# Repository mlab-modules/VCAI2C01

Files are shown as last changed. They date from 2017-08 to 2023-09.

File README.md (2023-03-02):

<!--- PrjInfo ---> <!--- Please remove this line after manually editing --->
<!--- 00a56be08b96043df9e37d6aff7b6990 --->
<!--- Created:2019-02-18 14:36:04.428293: ---> 
<!--- Author:: ---> 
<!--- AuthorEmail:: ---> 
<!--- Tags:: ---> 
<!--- Ust:: ---> 
<!--- Label --->
<!--- ELabel ---> 
<!--- Name:VCAI2C01A: --->
# VCAI2C01A
<!--- LongName --->
## AD converter voltage and current with I2C
<!--- ELongName ---> 

<!--- Lead --->
4-channel 18-bit AD converter voltage and current for industrial sensors. Ranges: 0-5V, 0-10V, 0-20mA, 4-20mA, 0-40 mA.
<!--- ELead ---> 

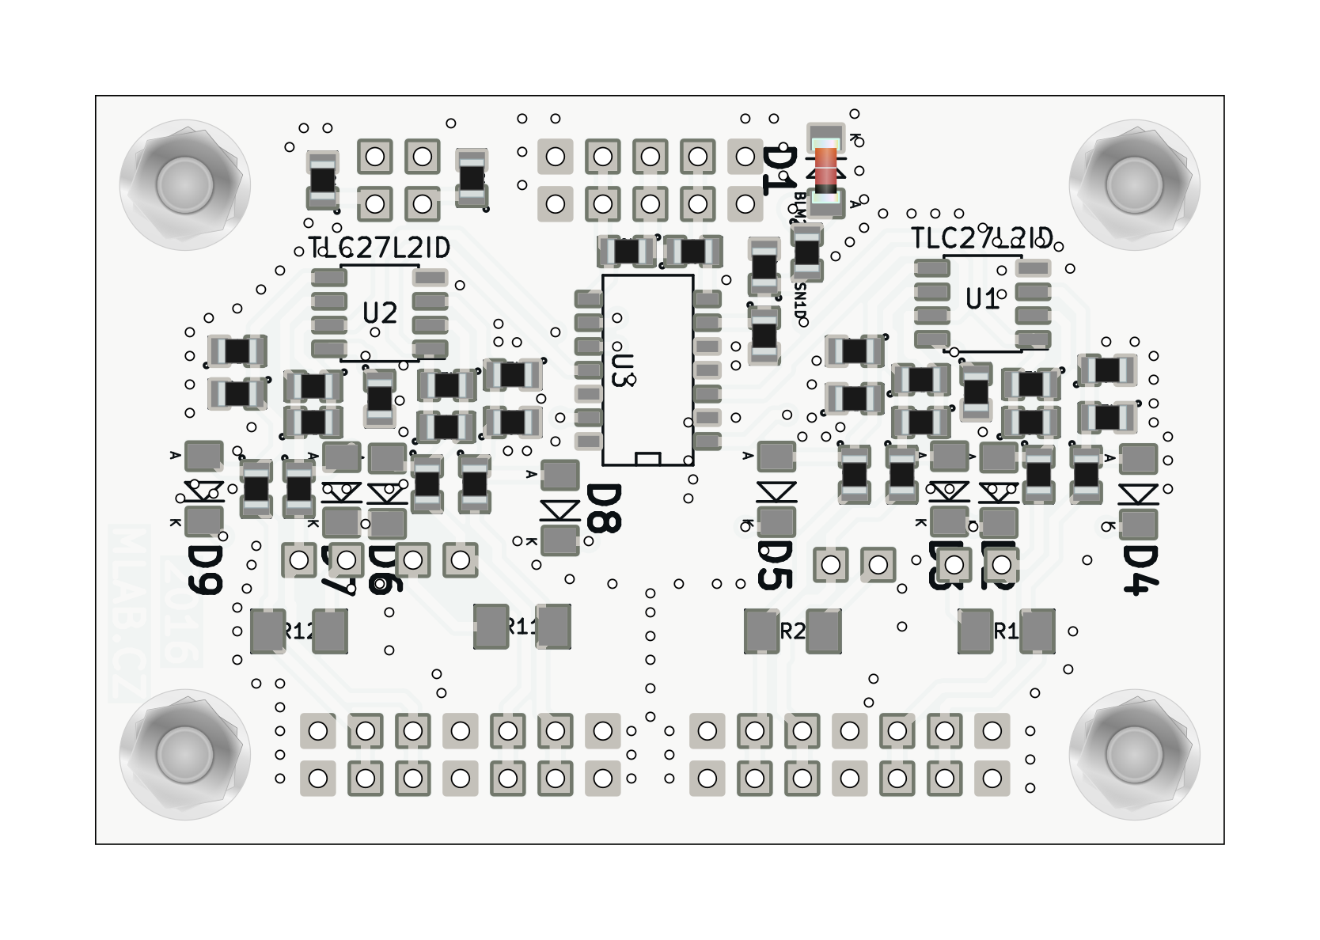
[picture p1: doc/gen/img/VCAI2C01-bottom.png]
VCAI2C01A bottom
 
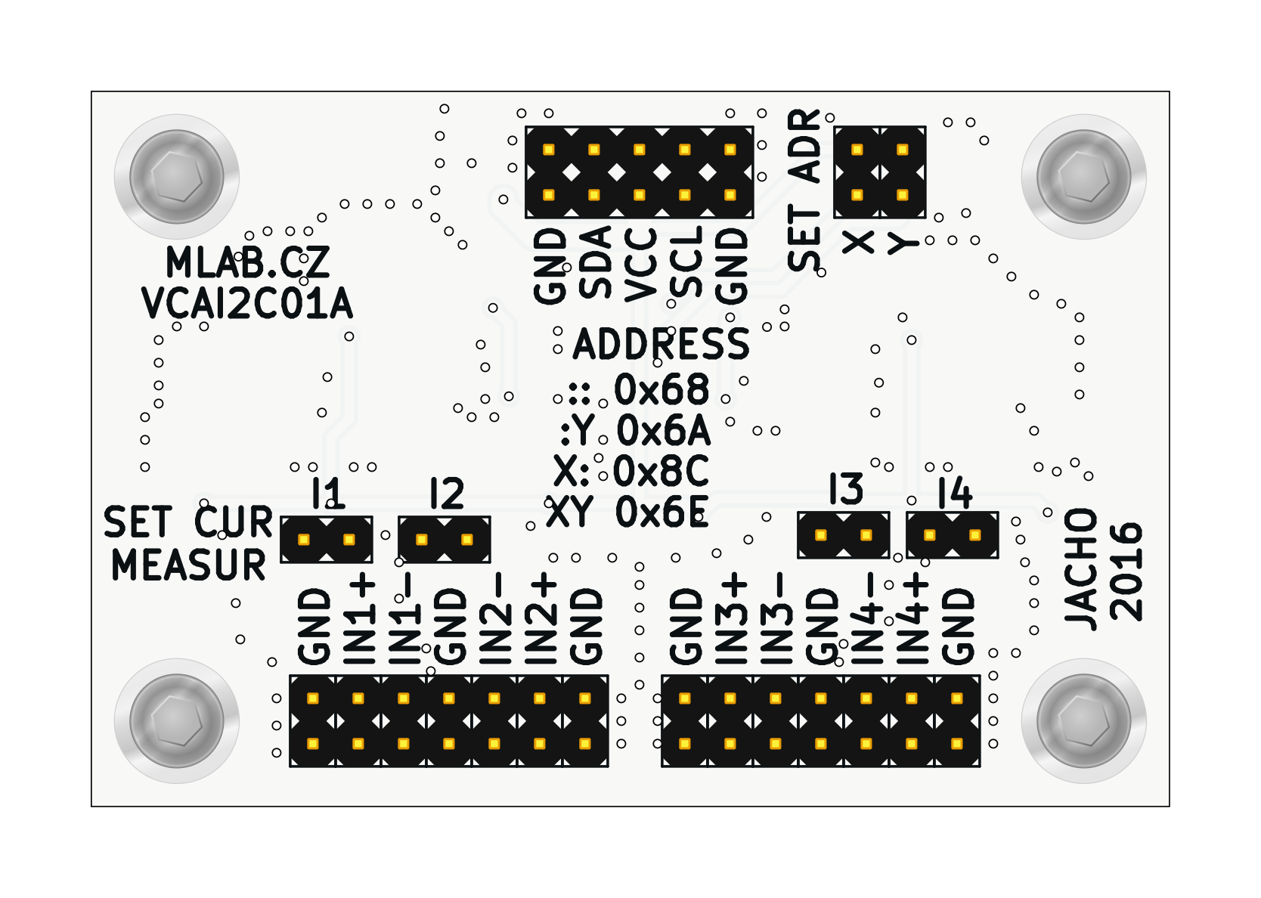
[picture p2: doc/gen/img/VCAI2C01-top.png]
VCAI2C01A bottom
 

<!--- Description --->
<!--- EDescription --->
<!--- Content --->
<!--- EContent --->
<sub><sup> Generated with [MLABweb](https://github.com/MLAB-project/MLABweb). (2019-02-18)</sup></sub>

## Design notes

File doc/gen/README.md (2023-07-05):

# PCB

Board size: 60.45x40.13 mm (2.38x1.58 inches)

- This is the size of the rectangle that contains the board
- Thickness: 1.6 mm (63 mils)
- Material: FR4
- Finish: HAL
- Layers: 2
- Copper thickness: 35 µm

Solder mask: TOP / BOTTOM

- Color: Green

Silk screen: TOP / BOTTOM

- Color: White

# Important sizes

Clearance: 0.25 mm (10 mils)

Track width: 0.3 mm (12 mils)

- By design rules: 0.2 mm (8 mils)

Drill: 0.5 mm (20 mils)

- Vias: 0.5 mm (20 mils) [Design: 0.4 mm (16 mils)]
- Pads: 1.0 mm (39 mils)
- The above values are real drill sizes, they add 0.1 mm (4 mils) to plated holes (PTH)

Via: 0.8/0.4 mm (31/16 mils)

- By design rules: 0.4/0.3 mm (16/12 mils)
- Micro via: yes [0.2/0.1 mm (8/4 mils)]
- Buried/blind via: yes
- Total: 162 (thru: 162 buried/blind: 0 micro: 0)

Outer Annular Ring: 0.15 mm (6 mils)

- By design rules: 0.26 mm (10 mils)

Eurocircuits class: 4B
- Using min drill 0.5 mm for an OAR of 0.15 mm

# General stats

Components count: (SMD/THT)

- Top: 0/25 (THT)
- Bottom: 49/0 (SMD)

Defined tracks:

- 0.3 mm (12 mils)
- 0.4 mm (16 mils)
- 0.5 mm (20 mils)
- 0.6 mm (24 mils)
- 0.7 mm (28 mils)
- 1.3 mm (51 mils)

Used tracks:

- 0.3 mm (12 mils) (231) defined: yes
- 0.5 mm (20 mils) (361) defined: yes
- 0.6 mm (24 mils) (21) defined: yes
- 0.7 mm (28 mils) (12) defined: yes
- 1.3 mm (51 mils) (11) defined: yes

Defined vias:

Used vias:

- 0.8/0.4 mm (31/16 mils) (Count: 162, Aspect: 2.0 A) defined: no

Holes (excluding vias):

- 0.89 mm (35 mils) (50)
- 3.0 mm (118 mils) (4)

Oval holes:

Drill tools (including vias and computing adjusts and rounding):

- 0.5 mm (20 mils) (162)
- 1.0 mm (39 mils) (50)
- 3.1 mm (122 mils) (4)

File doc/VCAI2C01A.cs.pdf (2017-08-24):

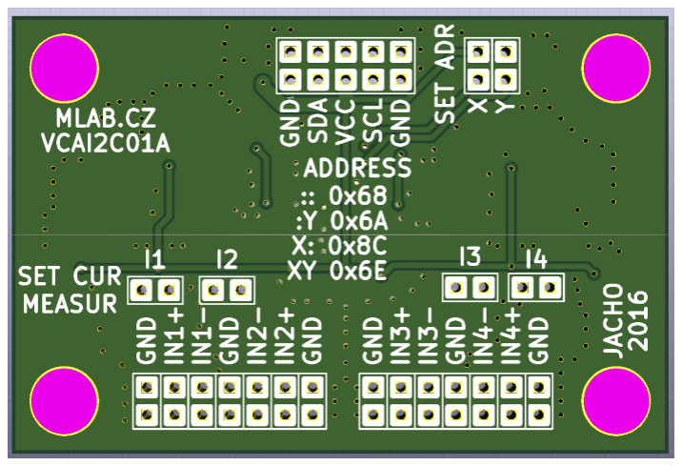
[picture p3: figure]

VCAI2C01A / 2016-10-04 / jacho/ http://www.mlab.cz | 1 / 5
VCAI2C01A | MLAB

# A/D převodník napětí a proudu s I2C

Jan Chroust

### Díky tomuto převodníku, je možné k systému založeném na modulech MLAB připojit standardní průmyslové senzory. Jedná se o

4 kanálový 18 bitový AD převodník.

# 1. Technické parametry

Parametr | Hodnota | Poznámka
Napájení | 5 V
Integrovaný obvod | MCP3424, TLC27L2ID
Využití | A/D převodník napětí a proudu
Rozsahy | 0-5V, 0-10V
| 0-20mA, 4-20mA, 0-40mA
Rozhraní | I2C
Rozměry | 60.45 x 40.13 x 16 mm | Výška nad základní deskou

VCAI2C01A | MLAB

# 2. Popis konstrukce

## 2.1. Popis

Jedná se o modul s 18 bitovým ∆∑ převodníkem. Umožňuje připojení standardních průmyslových senzorů, které využívají proudové smyčky, nebo napěťového výstupu. Komunikace s modulem probíhá přes I2C rozhraní. Na modulu je možné volit mezi čtveřicí adres. Pokud by bylo adres nedostatek, řešením je využití modulu I2CHUB02B. Pro aplikace, kde je potřeba větších vzdáleností v řádech desítek metrů od řídícího počítače, je k dispozici modul I2CDIFF01B. Kombinací modulů MLAB je možné navrhnout komplexní měřící zařízení.

### 2.1.1. Proudový režim

Pro kanály, kde chceme měřit proud je potřeba vložit jumper do řádky označené SET CUR MEASUR na příslušný kanál (I1, I2, I3, I4). Následně je možné na příslušný vstup připojit proudovou smyčku.

### 2.1.2. Napěťový režim

Jedná se o základní režim. Nesmí být vložen jumper do řádku s označením SET CUR MEASUR.

### 2.1.3. Volba I2C adresy

Na modulu je vyznačena tabulka I2C adres, které je možné volit konfigurací jumperů na hřebíncích označených SET ADR. Když není umístěn žádný jumper, tak adresa modulu je 0x68. Jedná se o 7bitovou adresu.

VCAI2C01A | MLAB

## 2.2. Zapojení

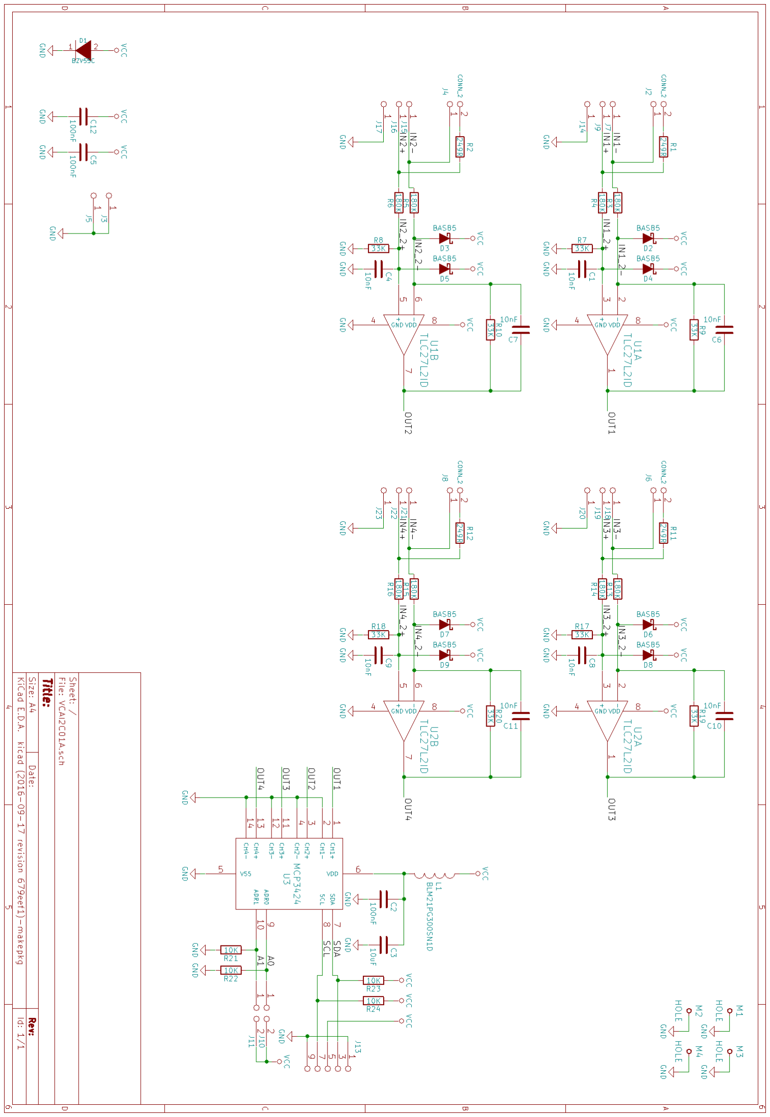
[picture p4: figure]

VCAI2C01A | MLAB

# 3. Osazení a oživení

## 3.1. Osazení

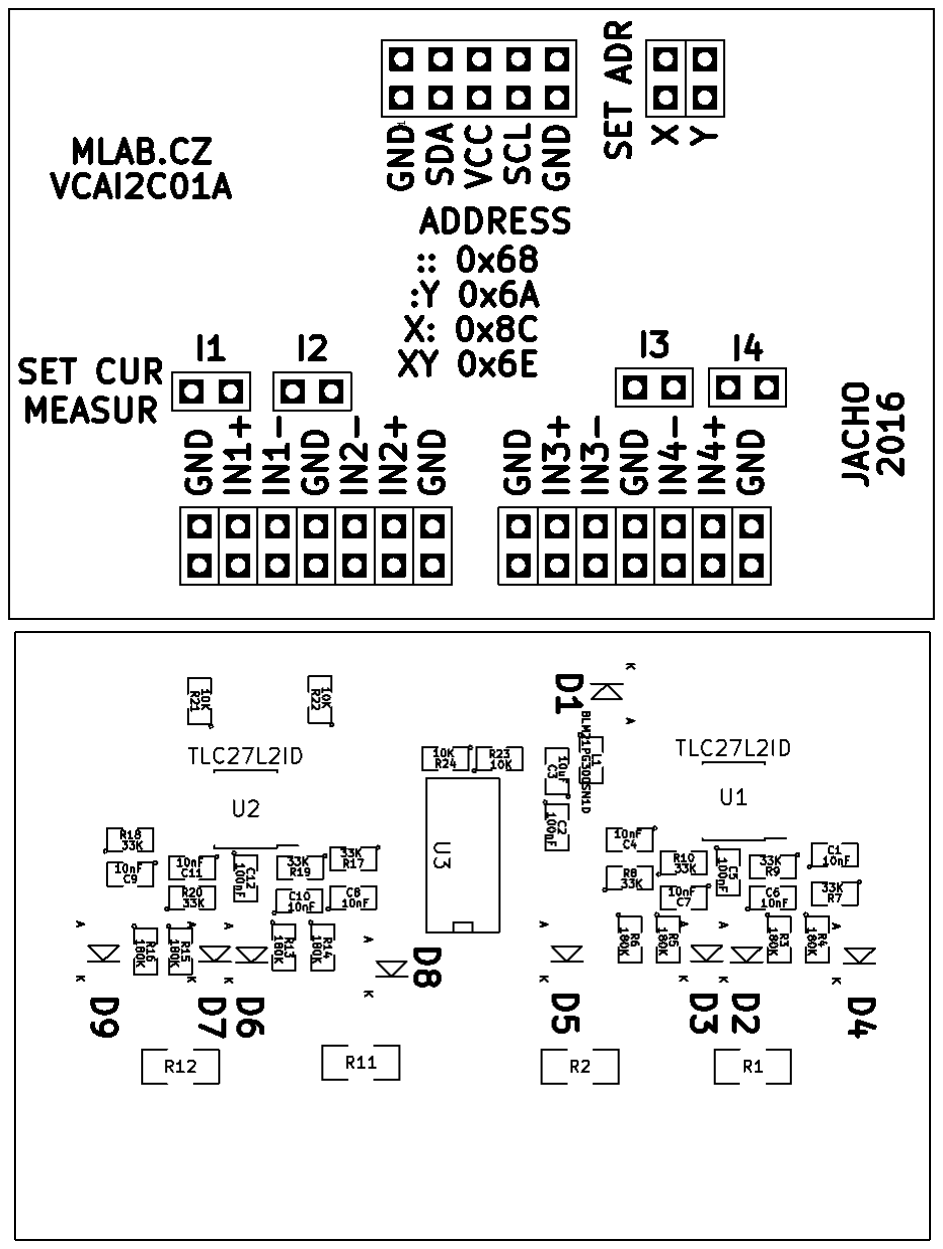
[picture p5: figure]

VCAI2C01A | MLAB

## 3.2. Rozpis součástek

Označení | Typ | Pouzdro | Počet
C1,C8,C6,C4,C7,C9,C10,C11 | 10nF | SMD-0805 | 8
R17,R19,R7,R8,R9,R10,R18,R20 | 33K | SMD-0805 | 8
U2,U1 | TLC27L2ID | SOIC-8_3.9x4.9mm_Pitch1.27mm | 2
R22,R21,R23,R24 | 10K | SMD-0805 | 4
D4,D2,D3,D5,D6,D7,D8,D9 | BAS85 | MiniMELF_Standard | 8
C2,C5,C12 | 100nF | SMD-0805 | 3
C3 | 10uF | SMD-0805 | 1
D1 | BZV55C | Diode-MiniMELF_Standard | 1
J2,J4,J6,J8 | CONN_2 | Straight_1x02 | 4
J10,J11 | JUMP2_2x1 | Straight_2x01 | 2
J13 | JUMP_5X2 | Straight_2x05 | 1
M1,M2,M3,M4 | HOLE | MountingHole_3mm | 4
R3,R4,R5,R6,R13,R14,R15,R16 | 180K | SMD-0805 | 8
U3 | MCP3424 | SOIC-14 | 1
J14,J15,J16,J17,J18,J19,J20,J21,J22,J23,J5 ,J7,J9 | JUMP_2x1 | Straight_1x02 | 13
J3 | JUMP_2x1 | Straight_2x01 | 1
L1 | BLM21PG300SN1D | SMD-0805 | 1
R1,R2,R11,R12 | 249R | SMD-1206 | 4

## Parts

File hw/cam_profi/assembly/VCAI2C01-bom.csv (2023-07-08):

Component | Description | Part | References | Value | Footprint | Quantity Per PCB | Datasheet
1 |  | C | C1C4C6C7C8C9C10C11 | 10nF | SMD-0805 | 8
2 |  | C | C2C5C12 | 100nF | SMD-0805 | 3
3 |  | C | C3 | 10uF | SMD-0805 | 1
4 |  | D_Schottky | D2D3D4D5D6D7D8D9 | BAS85 | MiniMELF_Standard | 8
5 |  | DIODE | D1 | BZV55C | Diode-MiniMELF_Standard | 1
6 |  | CONN_2 | J2J4J6J8 | CONN_2 | Straight_1x02 | 4
7 |  | JUMP2_2x1 | J10J11 | JUMP2_2x1 | Straight_2x01 | 2
8 |  | JUMP_2x1 | J5J7J9J14J15J16J17J18J19J20J21J22J23 | JUMP_2x1 | Straight_1x02 | 13
9 |  | JUMP_2x1 | J3 | JUMP_2x1 | Straight_2x01 | 1
10 |  | JUMP_5X2 | J13 | JUMP_5X2 | Straight_2x05 | 1
11 |  | INDUCTOR_SMALL | L1 | BLM21PG300SN1D | SMD-0805 | 1
12 |  | R | R1R2R11R12 | 249R | SMD-1206 | 4
13 |  | R | R21R22R23R24 | 10K | SMD-0805 | 4
14 |  | R | R7R8R9R10R17R18R19R20 | 33K | SMD-0805 | 8
15 |  | R | R3R4R5R6R13R14R15R16 | 180K | SMD-0805 | 8
16 |  | MCP3424 | U3 | MCP3424 | SOIC-14 | 1
17 |  | TLC27L2ID | U1U2 | TLC27L2ID | SOIC-8_3.9x4.9mm_Pitch1.27mm | 2

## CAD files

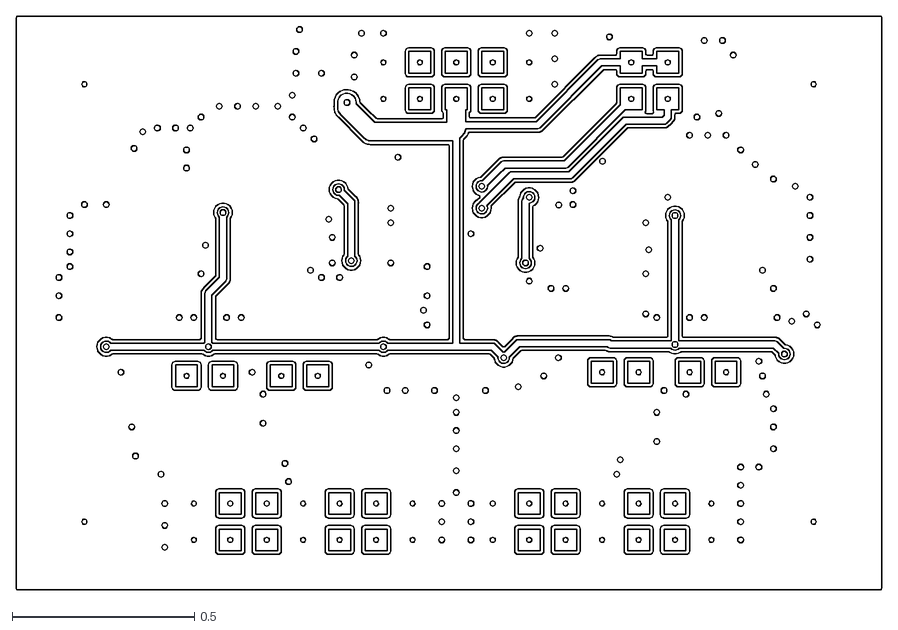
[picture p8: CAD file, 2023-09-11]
doc/gen/dxf/VCAI2C01-F_Cu.dxf
2.37 x 1.57

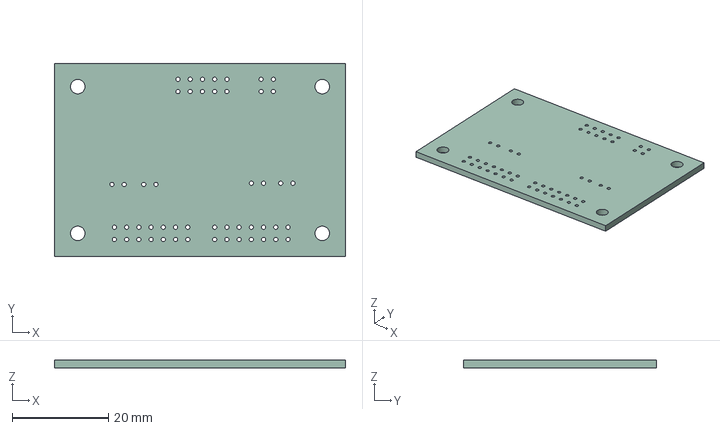
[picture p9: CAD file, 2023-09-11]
doc/gen/VCAI2C01.step
60.5 x 40.1 x 1.60 mm

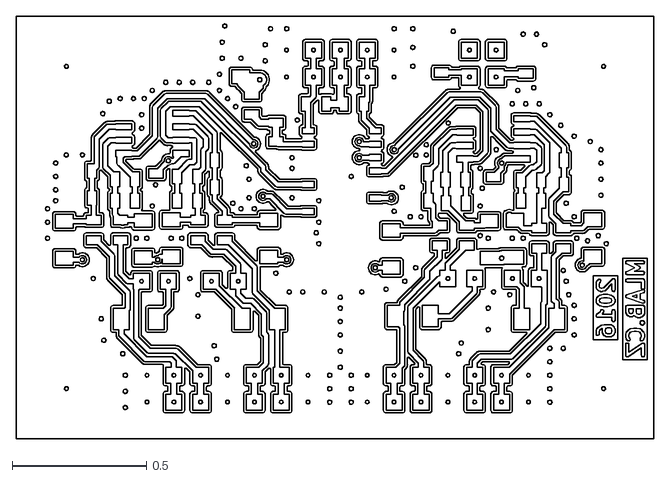
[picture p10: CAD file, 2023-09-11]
doc/gen/dxf/VCAI2C01-B_Cu.dxf
2.37 x 1.57

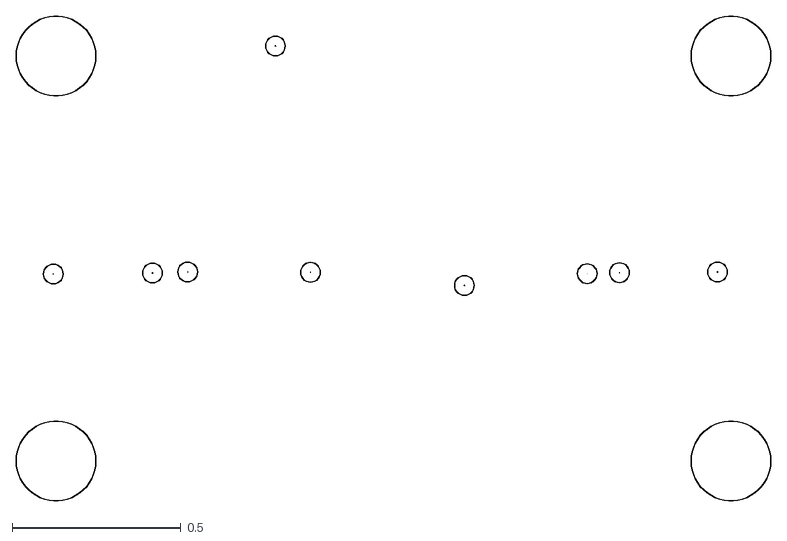
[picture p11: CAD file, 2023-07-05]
doc/gen/dxf/VCAI2C01-B_Adhesive.dxf
2.24 x 1.44

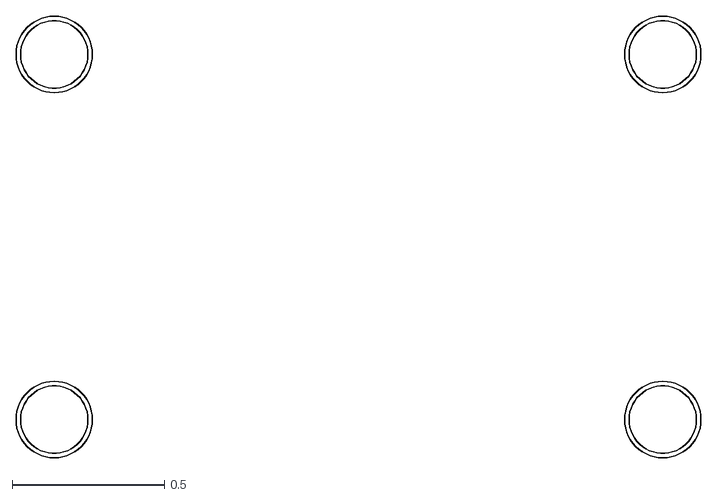
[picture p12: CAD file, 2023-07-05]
doc/gen/dxf/VCAI2C01-User_Comments.dxf
2.25 x 1.45

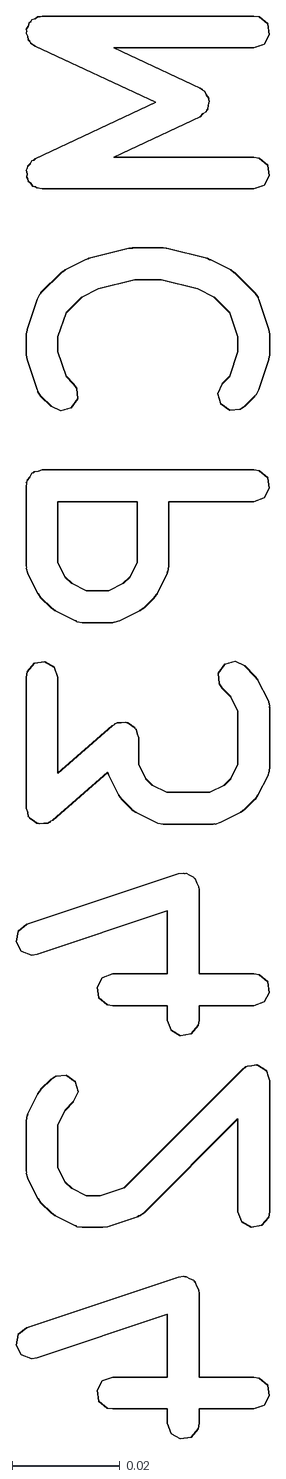
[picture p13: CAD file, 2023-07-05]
doc/gen/dxf/VCAI2C01-B_Fab.dxf
0.0471 x 0.265

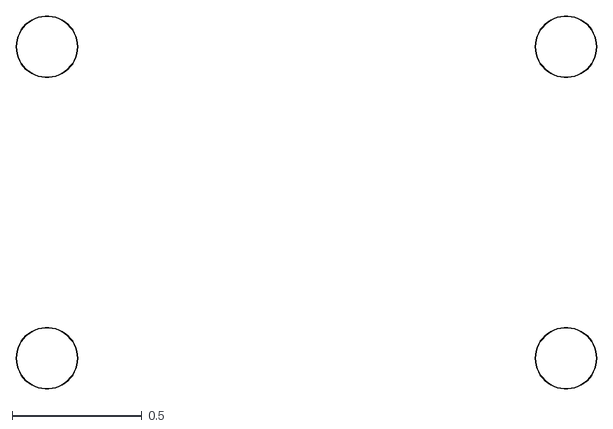
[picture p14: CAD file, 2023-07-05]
doc/gen/dxf/VCAI2C01-F_Adhesive.dxf
2.24 x 1.44

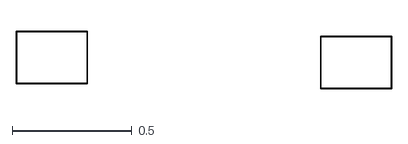
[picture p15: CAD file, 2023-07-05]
doc/gen/dxf/VCAI2C01-B_Courtyard.dxf
1.57 x 0.239

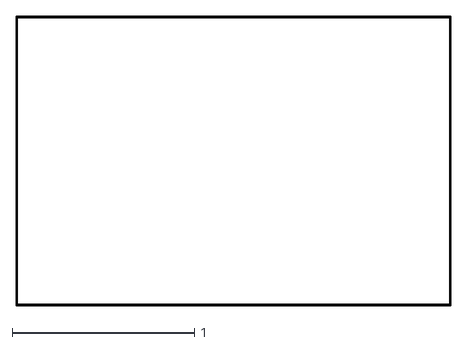
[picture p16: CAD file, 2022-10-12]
doc/gen/dxf/VCAI2C01-Edge_Cuts.dxf
2.39 x 1.59

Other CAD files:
doc/gen/dxf/VCAI2C01-User_Drawings.dxf
doc/gen/dxf/VCAI2C01-User_Eco2.dxf
doc/gen/dxf/VCAI2C01-F_Fab.dxf
doc/gen/dxf/VCAI2C01-User_Eco1.dxf
doc/gen/dxf/VCAI2C01-F_Courtyard.dxf
doc/gen/dxf/VCAI2C01-Margin.dxf
doc/gen/dxf/VCAI2C01-B_Mask.dxf
doc/gen/dxf/VCAI2C01-B_Paste.dxf
doc/gen/dxf/VCAI2C01-B_Silkscreen.dxf
doc/gen/dxf/VCAI2C01-F_Mask.dxf
doc/gen/dxf/VCAI2C01-F_Paste.dxf
doc/gen/dxf/VCAI2C01-F_Silkscreen.dxf

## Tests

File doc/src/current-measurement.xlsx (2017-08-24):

CH1 |  |  |  |  | CH2 |  |  |  |  | CH3 |  |  |  |  | CH4
ref[mA] | value | current[mA] | err[%] | err[mA] | ref[mA] | value | current[mA] | err[%] | err[mA] | ref[mA] | value | current[mA] | err[%] | err[mA] | ref[mA] | value | current[mA] | err[%] | err[mA]
25.1 | 18371 | 25.152 | 0.207 | 0.052 | 25.13 | 18420 | 25.219 | 0.353 | 0.089 | 25.04 | 18296 | 25.049 | 0.037 | 0.009 | 25.159 | 18429 | 25.231 | 0.287 | 0.072
20.05 | 14682 | 20.101 | 0.255 | 0.051 | 20.344 | 14908 | 20.411 | 0.327 | 0.067 | 20.28 | 14881 | 20.374 | 0.460 | 0.094 | 20.288 | 14857 | 20.341 | 0.260 | 0.053
15.017 | 11000 | 15.060 | 0.287 | 0.043 | 15 | 11008 | 15.071 | 0.472 | 0.071 | 15.06 | 11061 | 15.144 | 0.553 | 0.084 | 15.11 | 11070 | 15.156 | 0.304 | 0.046
10.051 | 7375 | 10.097 | 0.458 | 0.046 | 10.013 | 7353 | 10.067 | 0.537 | 0.054 | 10.067 | 7411 | 10.146 | 0.783 | 0.079 | 10.053 | 7372 | 10.093 | 0.397 | 0.040
5.008 | 3682 | 5.041 | 0.656 | 0.033 | 5.038 | 3707 | 5.075 | 0.735 | 0.037 | 5.033 | 3726 | 5.101 | 1.339 | 0.068 | 5.01 | 3682 | 5.041 | 0.616 | 0.031
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

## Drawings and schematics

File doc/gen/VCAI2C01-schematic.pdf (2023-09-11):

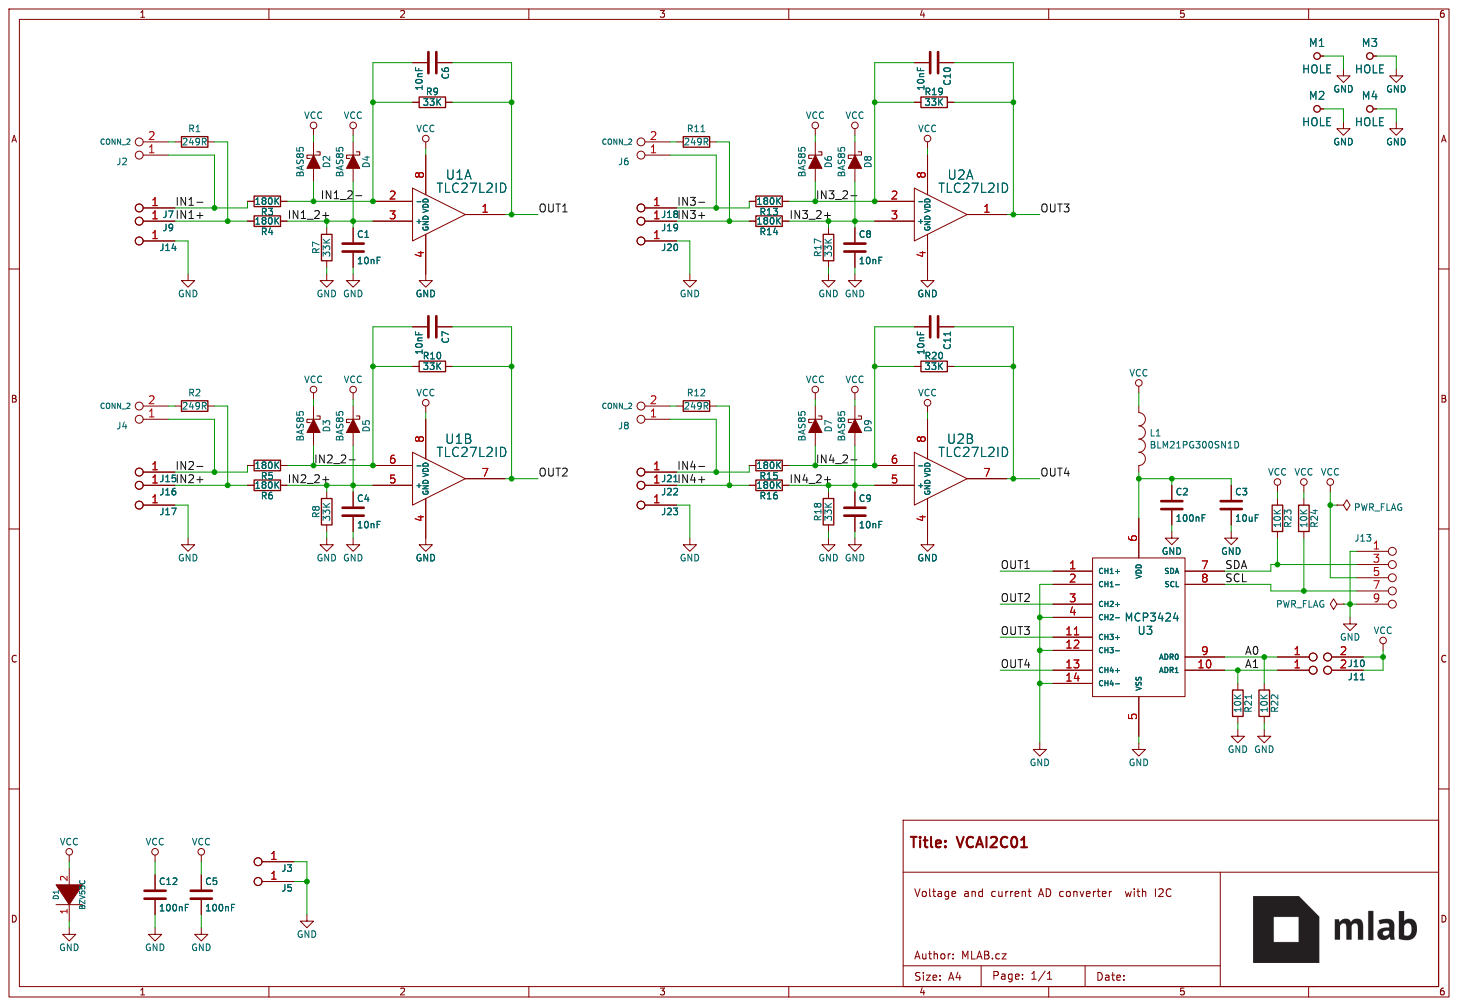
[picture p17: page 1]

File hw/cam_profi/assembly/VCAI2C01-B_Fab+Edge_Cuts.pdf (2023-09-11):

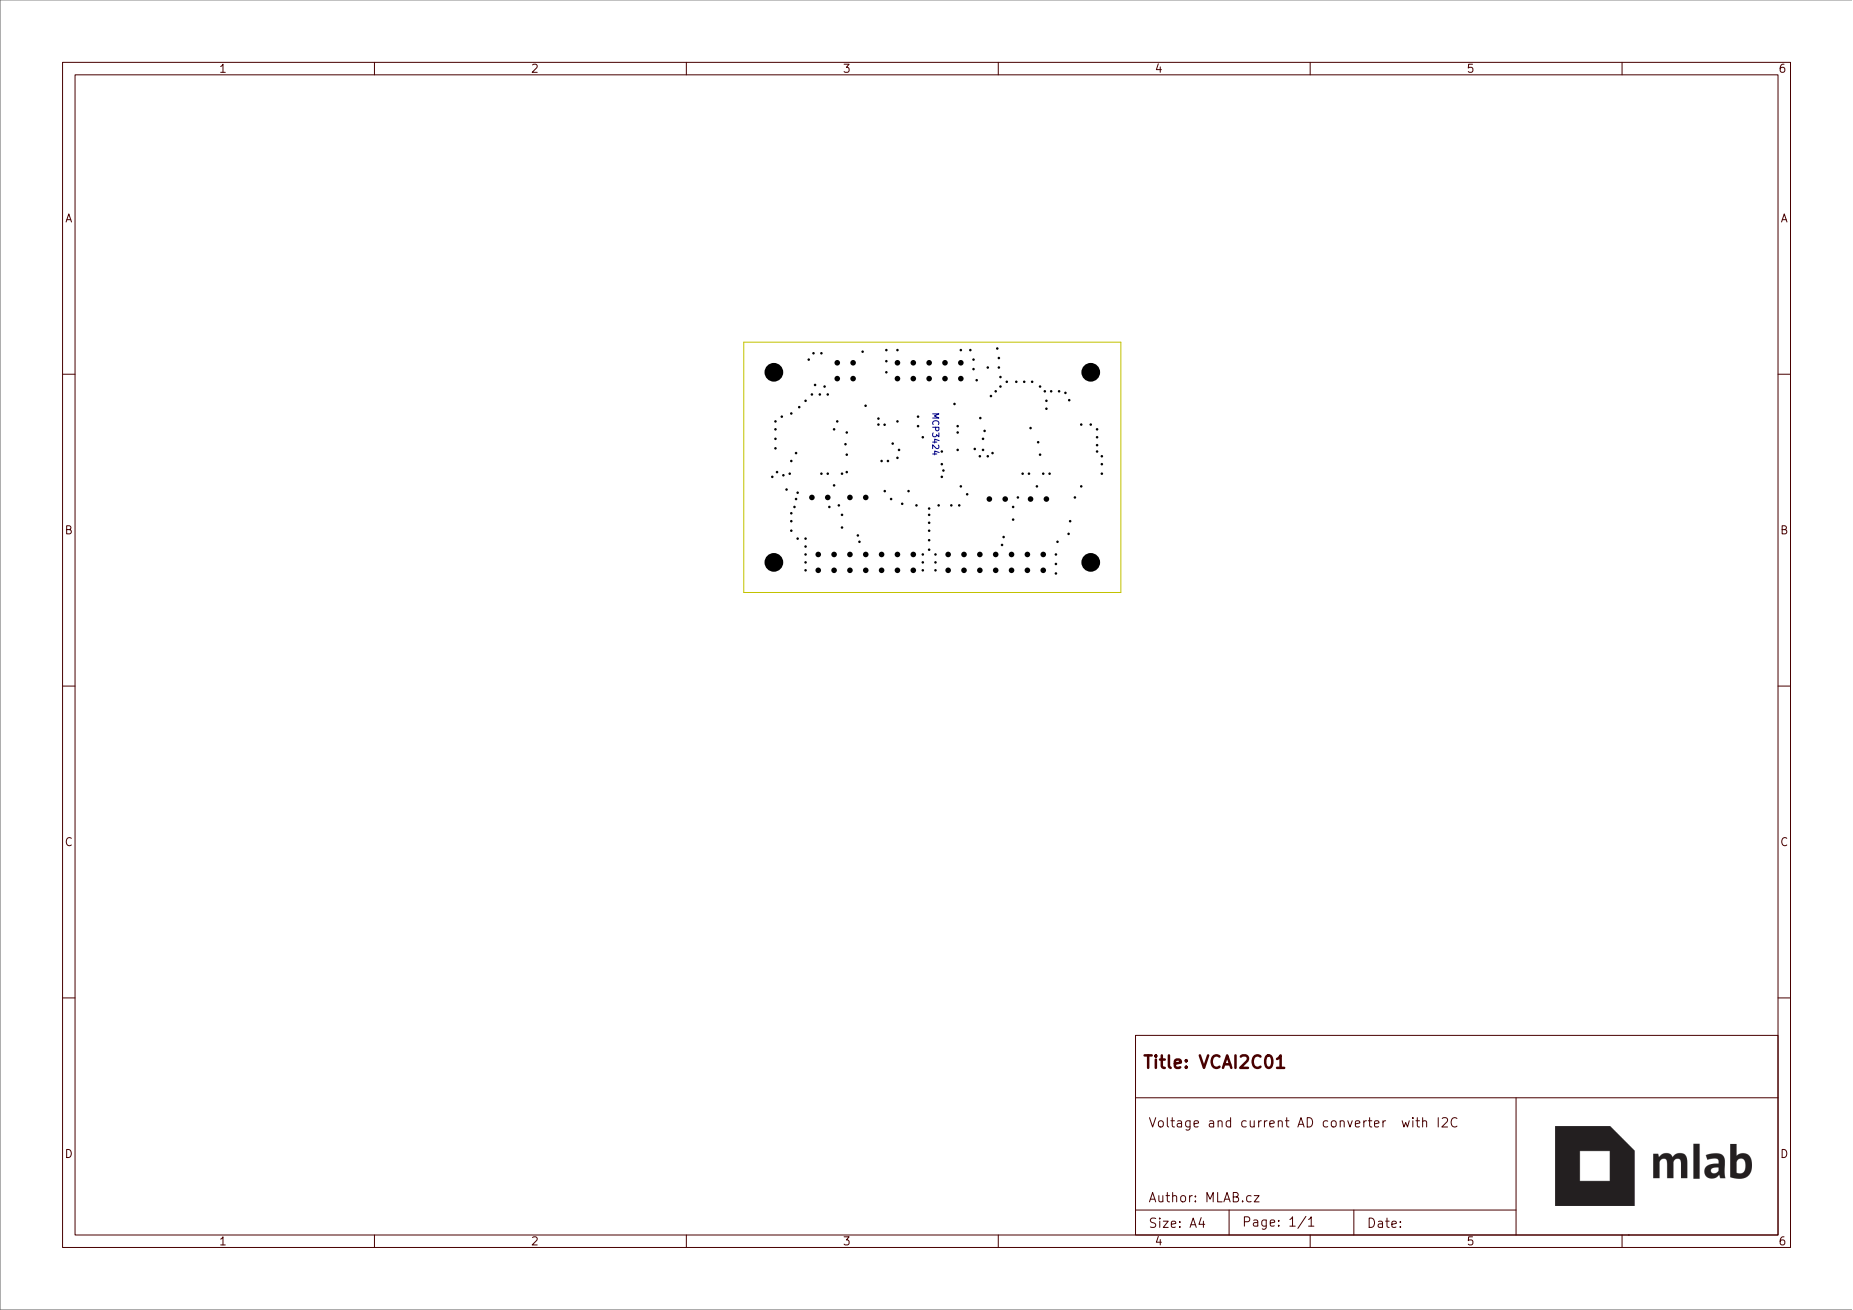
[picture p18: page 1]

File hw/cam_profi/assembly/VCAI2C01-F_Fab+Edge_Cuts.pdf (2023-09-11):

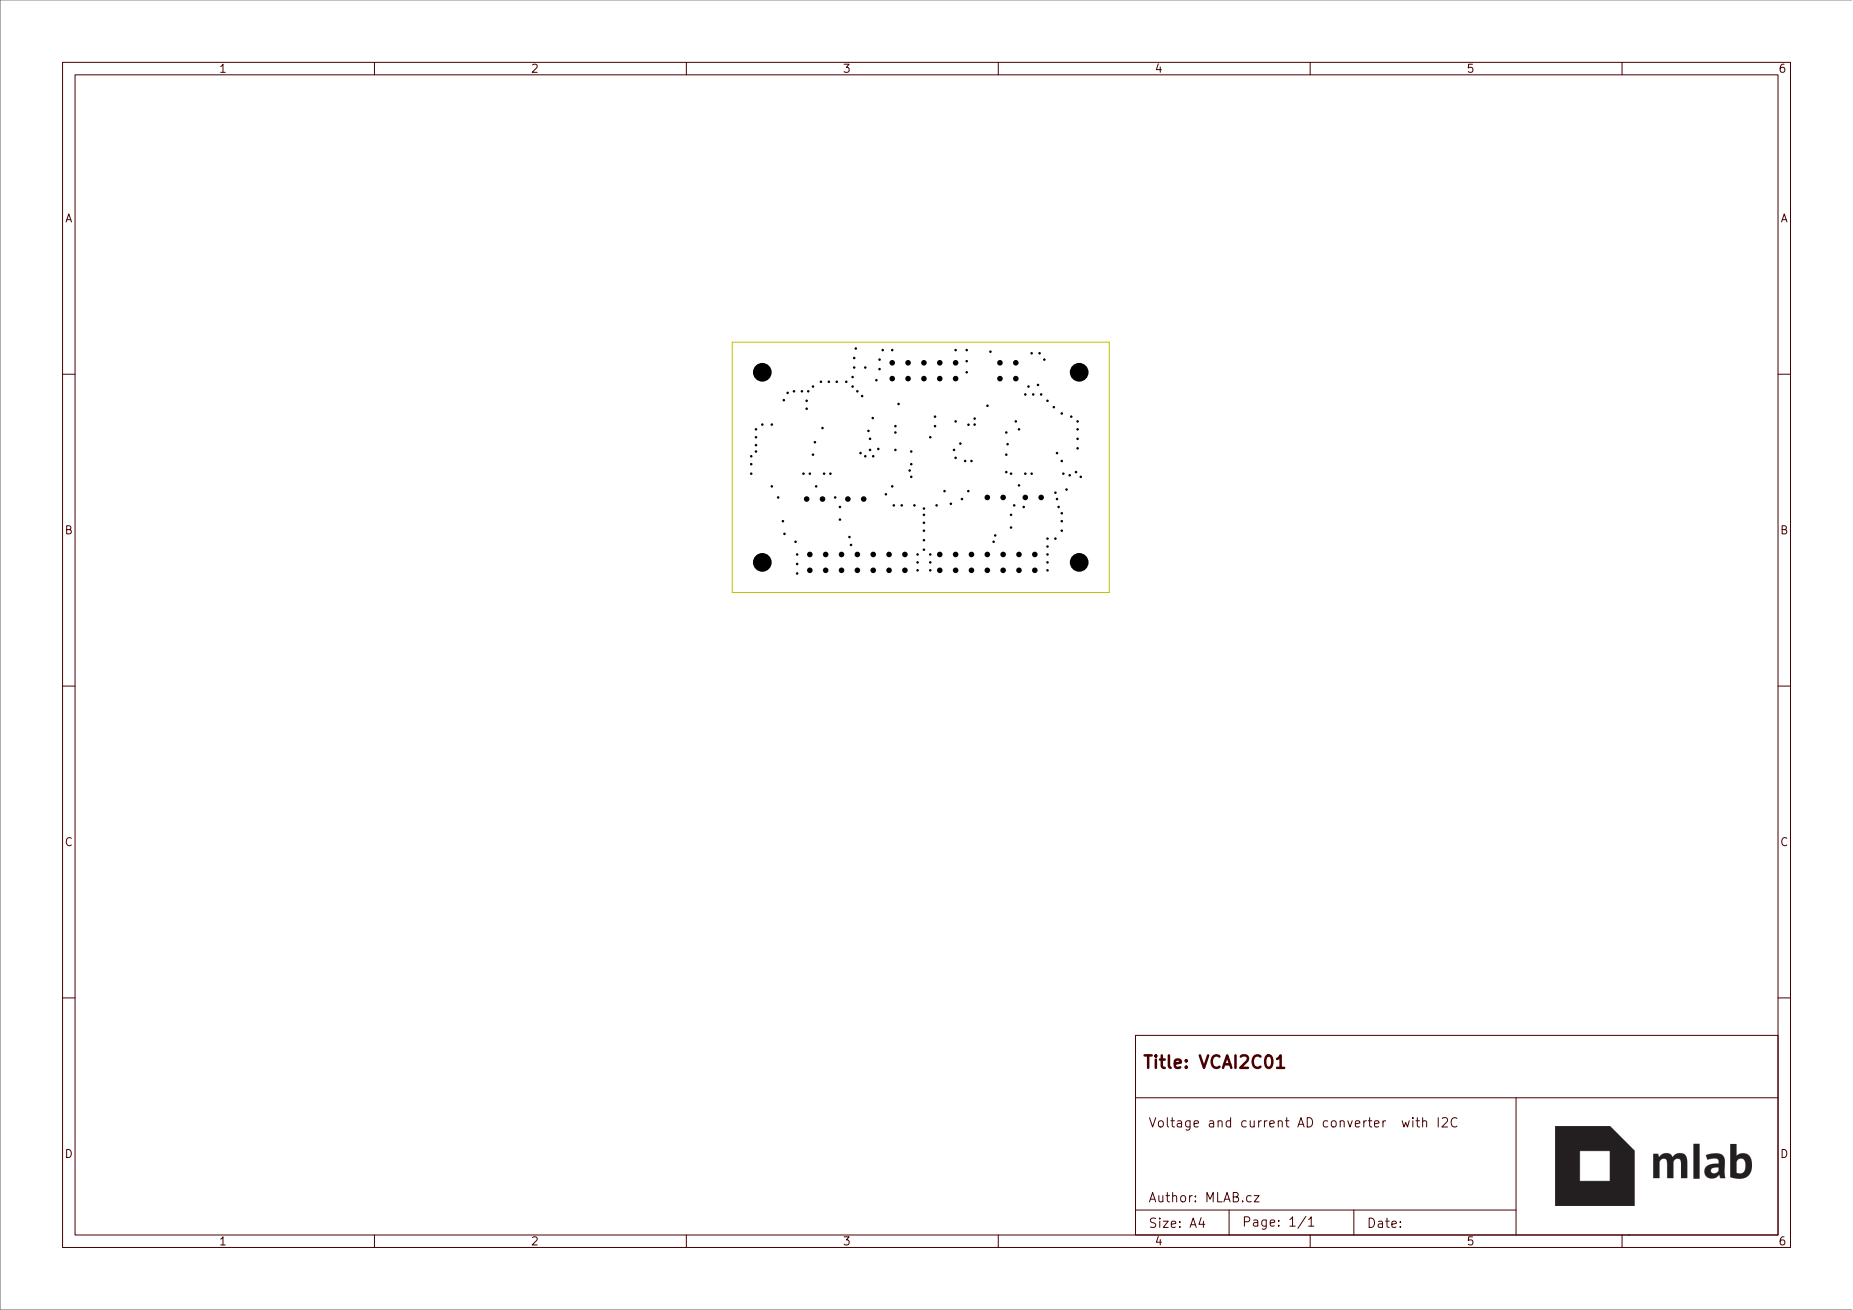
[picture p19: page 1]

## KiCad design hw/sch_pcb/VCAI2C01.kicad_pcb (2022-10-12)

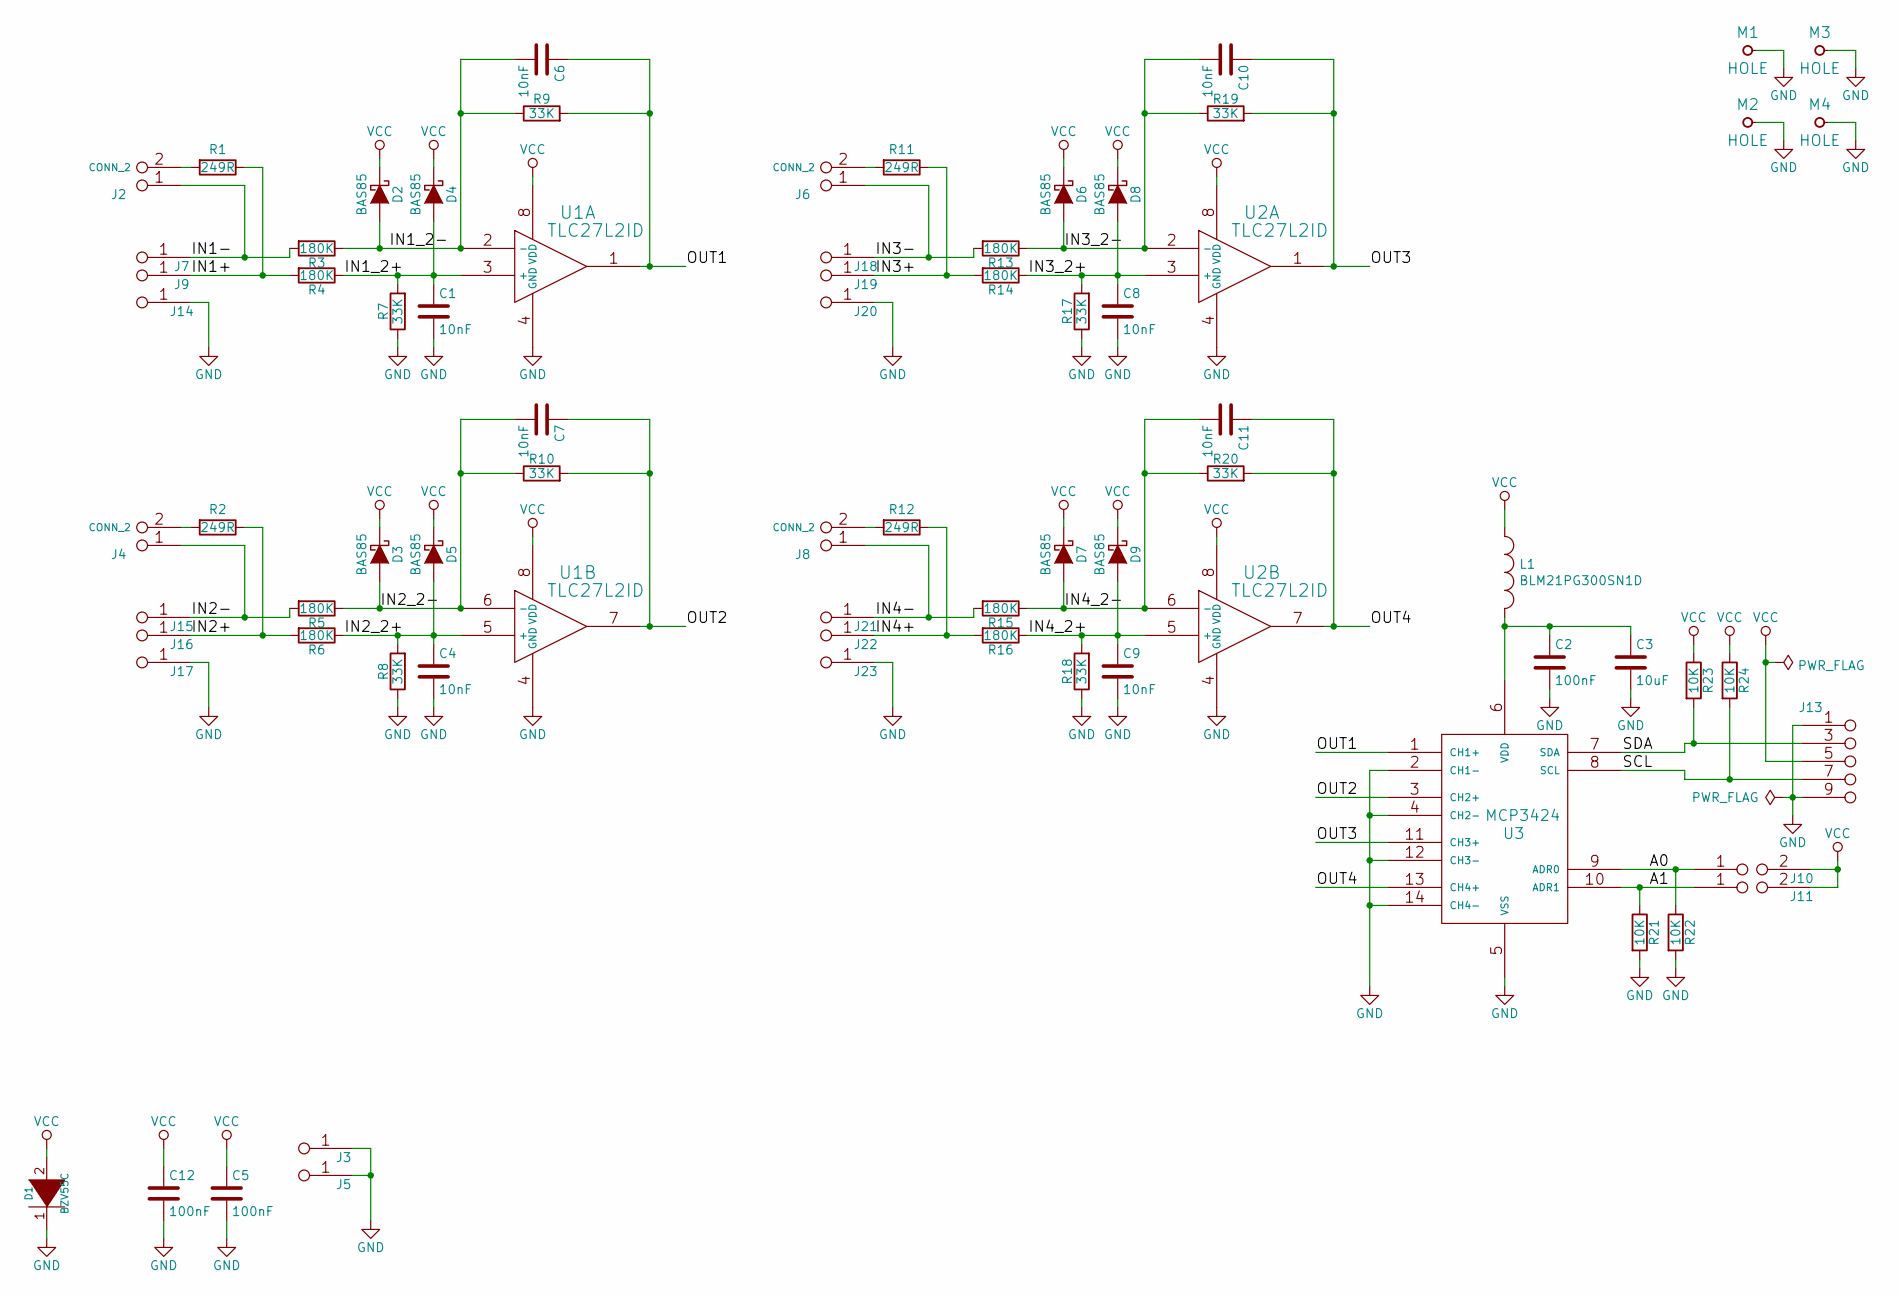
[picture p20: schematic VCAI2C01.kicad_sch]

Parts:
C1, C4, C6, C7, C8, C9, C10, C11: 10nF; SMD-0805
C2, C5, C12: 100nF; SMD-0805
C3: 10uF; SMD-0805
D1: BZV55C; Diode-MiniMELF_Standard
D2, D3, D4, D5, D6, D7, D8, D9: BAS85; MiniMELF_Standard
J2, J4, J6, J8: CONN_2; Straight_1x02
J3: JUMP_2x1; Straight_2x01
J5, J7, J9, J14, J15, J16, J17, J18, J19, J20, J21, J22, J23: JUMP_2x1; Straight_1x02
J10, J11: JUMP2_2x1; Straight_2x01
J13: JUMP_5X2; Straight_2x05
L1: BLM21PG300SN1D; SMD-0805
M1, M2, M3, M4: HOLE; MountingHole_3mm
R1, R2, R11, R12: 249R; SMD-1206
R3, R4, R5, R6, R13, R14, R15, R16: 180K; SMD-0805
R7, R8, R9, R10, R17, R18, R19, R20: 33K; SMD-0805
R21, R22, R23, R24: 10K; SMD-0805
U1, U2: TLC27L2ID; SOIC-8_3.9x4.9mm_Pitch1.27mm
U3: MCP3424; SOIC-14

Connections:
/A0: J10.1, R22.1, U3.9 (ADR0)
/A1: J11.1, R21.1, U3.10 (ADR1)
/IN1+: J9.1, J9.2, R1.1, R4.2
/IN1-: J2.1, J7.1, J7.2, R3.2
/IN1_2+: C1.1, D4.2 (A), R4.1, R7.2, U1.3 (+)
/IN1_2-: C6.2, D2.2 (A), R3.1, R9.1, U1.2 (-)
/IN2+: J16.1, J16.2, R2.1, R6.2
/IN2-: J4.1, J15.1, J15.2, R5.2
/IN2_2+: C4.1, D5.2 (A), R6.1, R8.2, U1.5 (+)
/IN2_2-: C7.2, D3.2 (A), R5.1, R10.1, U1.6 (-)
/IN3+: J19.1, J19.2, R11.1, R14.2
/IN3-: J6.1, J18.1, J18.2, R13.2
/IN3_2+: C8.1, D8.2 (A), R14.1, R17.2, U2.3 (+)
/IN3_2-: C10.2, D6.2 (A), R13.1, R19.1, U2.2 (-)
/IN4+: J22.1, J22.2, R12.1, R16.2
/IN4-: J8.1, J21.1, J21.2, R15.2
/IN4_2+: C9.1, D9.2 (A), R16.1, R18.2, U2.5 (+)
/IN4_2-: C11.2, D7.2 (A), R15.1, R20.1, U2.6 (-)
/OUT1: C6.1, R9.2, U1.1, U3.1 (CH1+)
/OUT2: C7.1, R10.2, U1.7, U3.3 (CH2+)
/OUT3: C10.1, R19.2, U2.1, U3.11 (CH3+)
/OUT4: C11.1, R20.2, U2.7, U3.13 (CH4+)
/SCL: J13.7, J13.8 (7), R24.2, U3.8 (SCL)
/SDA: J13.3 (4), J13.4, R23.2, U3.7 (SDA)
GND: C1.2, C2.2, C3.2, C4.2, C5.2, C8.2, C9.2, C12.2, D1.1 (K), J3.1, J3.2, J5.1, J5.2, J13.1 (2), J13.2, J13.9 (10), J13.10, J14.1, J14.2, J17.1, J17.2, J20.1, J20.2, J23.1, J23.2, M1.1, M2.1, M3.1, M4.1, R7.1, R8.1, R17.1, R18.1, R21.2, R22.2, U1.4 (GND), U2.4 (GND), U3.2 (CH1-), U3.4 (CH2-), U3.5 (VSS), U3.12 (CH3-), U3.14 (CH4-)
unnamed: C2.1, C3.1, L1.2, U3.6 (VDD)
unnamed: J2.2 (PM), R1.2
unnamed: J4.2 (PM), R2.2
unnamed: J6.2 (PM), R11.2
unnamed: J8.2 (PM), R12.2
VCC: C5.1, C12.1, D1.2 (A), D2.1 (K), D3.1 (K), D4.1 (K), D5.1 (K), D6.1 (K), D7.1 (K), D8.1 (K), D9.1 (K), J10.2, J11.2, J13.5 (6), J13.6, L1.1, R23.1, R24.1, U1.8 (VDD), U2.8 (VDD)

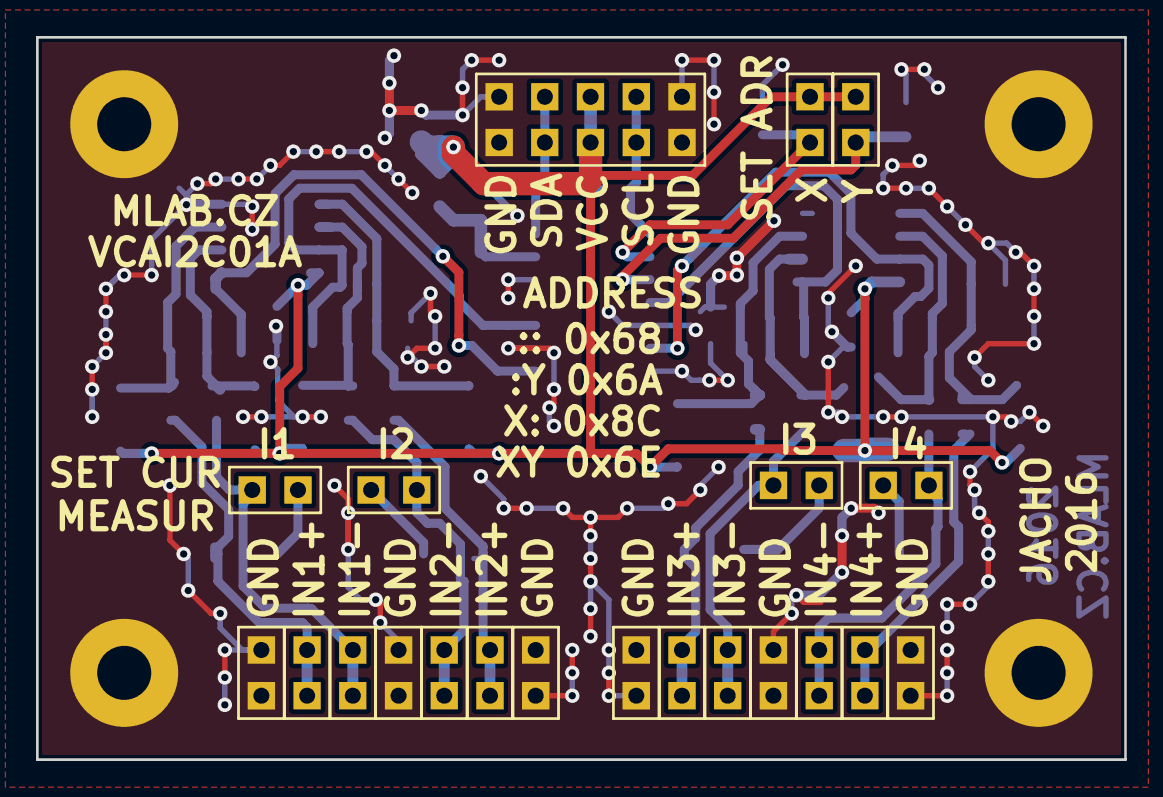
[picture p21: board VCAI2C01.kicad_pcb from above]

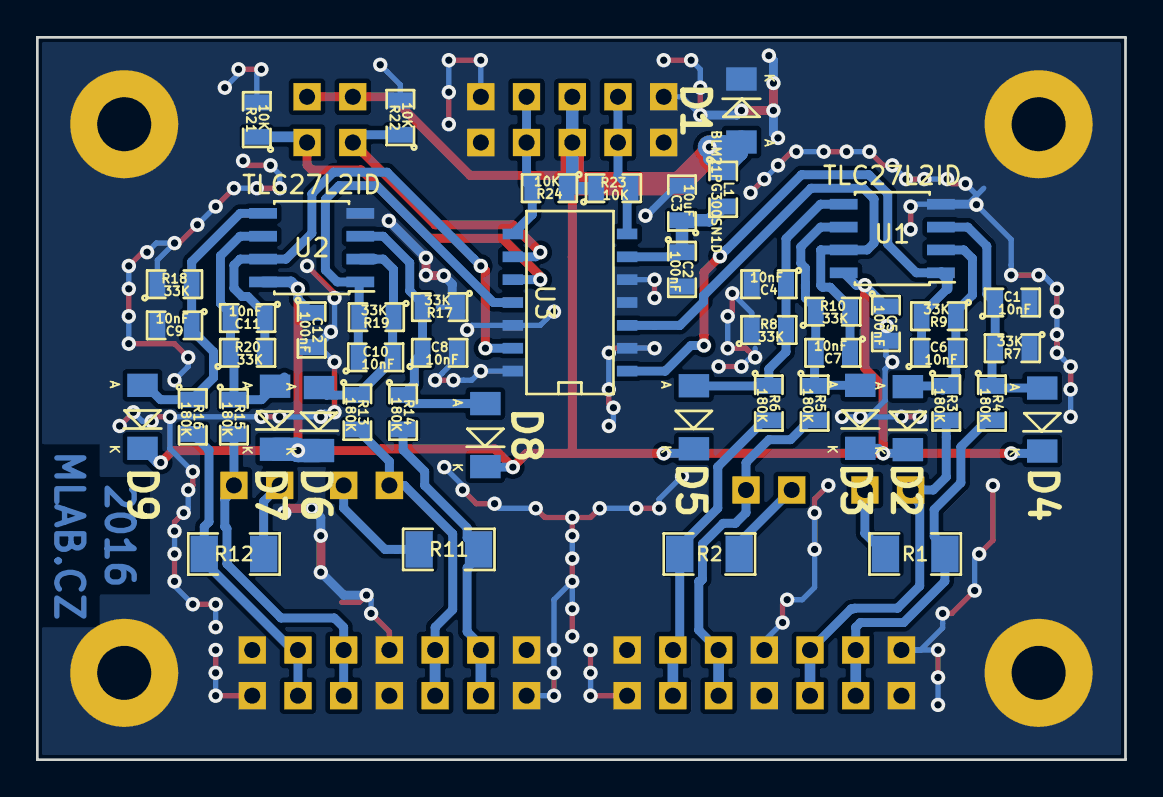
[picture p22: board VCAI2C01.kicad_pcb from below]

Board: 2 copper layers, 60.5 x 40.1 mm, 74 parts (49 on the bottom side), 31 nets.

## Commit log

2017-08-24 Microcontrollers and processors moved to separate directory.
    [VCAI2C01A.kicad_pcb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]
2022-07-12 Update to kicad 6.0 Activate github workflow.
    [VCAI2C01A.kicad_pcb, VCAI2C01A.kicad_sch, VCAI2C01A.sch]
2022-07-12 Update actions products
    [VCAI2C01A-B_Adhesive.dxf, VCAI2C01A-B_Courtyard.dxf, VCAI2C01A-B_Cu.dxf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]
2022-10-12 Cleanup copper pour layout. Add powerflags to schematics.
    [VCAI2C01A.kicad_pcb, VCAI2C01A.kicad_sch]
2022-10-12 Move Front silkscreen back on board.
    [VCAI2C01A.kicad_pcb]
2023-03-02 Rename to the new MLAB convention.
    [VCAI2C01.kicad_pcb, VCAI2C01.kicad_sch]
